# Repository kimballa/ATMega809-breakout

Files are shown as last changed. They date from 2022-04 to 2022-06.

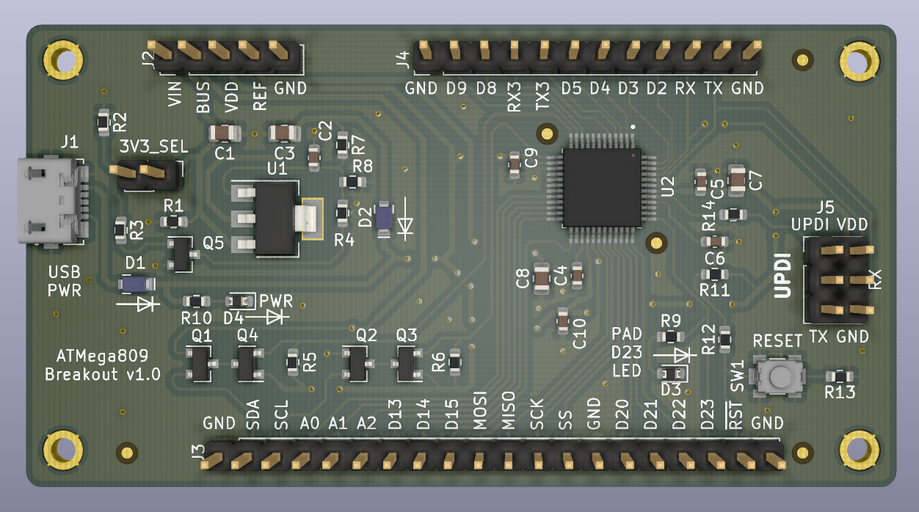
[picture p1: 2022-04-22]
fab runs/v1.0-2022-04-21/PCB-rendering.png

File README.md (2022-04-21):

# ATMega809 breakout board

PCB design for Atmel AVR ATMega809 breakout board. Capabilities compatible
with Arduino Nano Every (ATMega4809) and all other `ATMega{8/16/32/48}09`
and `x19` MCUs.

This provides more breakout pins from the 48-pin TQFP MCU than Nano Every
or other Arduinos.

## Power

Power can be supplied in 3 ways:

* The USB port `VUSB` is directly passed (unregulated) to the MCU
* Power on `VIN` will power a regulator that can operate at 5V0 or 3V3.
* Directly provide power to the `VDD` pin (unregulated)

### Caution!

Do not provide power to the regulator through `VIN` at the same time as
providing USB power through `VUSB`.

There are protection diodes so it should not immediately fail, but there is no
regulator shut-off circuit that detects USB power, so there may be unanticipated
consequences, especially if you plug in the USB power while the device is turned
on already by VIN.

This is especially true if the regulator is configured for 3V3, as the MCU will
immediately see its supply voltage increase while running.

`VDD` is also exposed on pin 15. You can use this to source power from the
linear regulator or to sink power back to the MCU. There is no diode or polyfuse
on this (or any) power bus of the device. Do not drive power into the device
through this pin at the same time as the regulator is powered.

### Configurable Regulator

The device is powered through an NCP1117LP adjustable 1A linear regulator.

This is configured for 5V0 operation by default. Closing the `3V3_SEL` jumper will
reconfigure it for 3V3. A task best performed with the device unpowered.

* If powering the device for 5V0, you must supply 6.5V or greater on `VIN`
* If powering the device for 3V3, you must supply 5.0V or greater on `VIN`
* `VIN` absolute maximum rating is 16V. For safe thermal operation, target
  `VDD + 3V` or less.

### Power limits and thermal capacity

You can draw power from the regulator's output `VDD` on pin 15. The total
power available (including MCU power budget) is 1A.

The ATMega809 can drive up to 15mA per pin in 5V0 mode, and 7.5mA in 3V3.
Absolute maximum rated drive per pin is +/-40mA. MCU absolute maximum VDD pin
input is 200mA.

The main limit to current is based on the LDO's thermal regulation capability.
LDO power dissipation in this implementation has an absolute maximum 825 mW. LDO
power dissipated is given by `(VIN - VDD - 0.35V)(IDD)`. Keeping `VIN` as close
to the 6.5V or 5.0V supply requirement gives more headroom for more current.

If VDD = 5V0 and VIN = 6V5, maximum current is 715 mA.

If VDD = 3V3 and VIN = 5V0, maximum current is 610 mA.

## Clock speed configuration

The MCU boots with `CLK_MAIN` driven by the `OSC20M` oscillator which is in
either 20MHz or 16MHz mode (check `OSCFUSE` bits to see how it is programmed),
with a `CLKDIV` of 6.

During boot, Arduino will disable the CLKDIV so your sketch is running at
the full 20 or 16MHz.

If operating in low-voltage 3V3 mode, the maximum safe clock speed is 10MHz.  So
a `CLKDIV` of at least 2 must be applied. If using an Arduino sketch on an
Arduino core compiled with default settings, the Arduino `init()` function will
fully unleash the clock divider for at least a short time before your `setup()`
method has time to pull it back to a divider of 2, which may cause boot
instability. Compiling the core with `-DFCPU=10000000` will tell Arduino to
unthrottle the clock only as far as a divider of 2.

## Level-shifting I2C Bus

The breakout board offers I2C on the `SDA`/`SCL` pins. A dual-transistor buffer
isolates the pull-up voltages seen on these pins from those seen by the MCU.
That is, a 3V3 network can communicate with an MCU operating at 5V0 or vice
versa.

You must supply power to the `VBUS` pin in order to activate the buffer and
communicate over I2C. Otherwise the external I2C bus will be fully isolated from
the MCU I2C bus. If the MCU and the external circuit are operating at the same
voltage you can connect `VBUS` to `VDD`.

You must apply external pull-up resistors to `SDA` and `SCL` to use I2C.
Typical resistor value is 4K7. The bus capacitance added by the breakout
board is typically 36 pF (per [PJA3438
datasheet](https://www.panjit.com.tw/upload/datasheet/PJA3438-AU.pdf))
[plus capacitance added by header pin, flying leads, etc].

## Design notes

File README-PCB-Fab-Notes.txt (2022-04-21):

Hello,

Thank you for making my PCB! I'm looking forward to seeing the results.

Here are a few manufacturing notes:

* U2 is 48-pin TQFP. 0.22mm between pins. Please eliminate solder dams in U2.

* USB Connector J1 goes right to the PCB edge. Molex MPN 0473461001. This does /not/ have flanges hanging down, it should lay flat on surface. Please let me know if this is a problem. 

* I have added 3 board fiducials and 2 local fiducials for U2. If these interfere with your localizing system I can remove them for you.

* Please note slightly rounded corners for edge milling.

If you have any questions, or there are difficulties to address please send me an email.

Thank you,
Aaron Kimball
akimball83@gmail.com

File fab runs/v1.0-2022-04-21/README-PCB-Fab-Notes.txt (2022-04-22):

Hello,

Thank you for making my PCB (ATMega809 Breakout)! I'm looking forward to seeing the results.

Here are a few manufacturing notes:

* U2 is 48-pin TQFP. 0.22mm space between pads. Please eliminate solder dams in U2.

* USB Connector J1 goes right to the PCB edge. Molex MPN 0473461001. This does /not/ have flanges hanging down, it should lay flat on surface. Please let me know if this is a problem. 

* I have added 3 board fiducials and 2 local fiducials for U2. If these interfere with your localizing system I can remove them for you and regenerate the files.

* For J2-J4 & JP1 assembly these just need cuttable male header pin strips of appropriate length. qty 39 is the total number of pins -- but only 4 strips/parts to place.

* Please note slightly rounded corners for edge milling.

* Part substitution for resistors is OK as long as they are 1% tolerance. For capacitors, LEDs, diodes, transistors etc. substitution only OK if all parameters in the "description" column in the BOM are met. The LEDs in particular are tuned for a very low test current requirement at 1.9V drop. The ATMEGA809 is acceptable in any of four part numbers: ATMEGA809-AF, ATMEGA809-AFR, ATMEGA809-AU, ATMEGA809-AUR. The -R's are on cut tape, AF/AU are in trays. This must be a genuine Microchip part.

I have included an electrical schematic pdf as well as a 3-d render of what the completed board should look like (png file). The BOM file (Excel) has a mapping from part ids to MPNs and descriptions. If you have any questions, or there are difficulties to address please send me an email.

Thank you,
Aaron Kimball
akimball83@gmail.com

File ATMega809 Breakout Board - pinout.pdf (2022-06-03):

## ATMega809 breakout board 24 digital I/O pins available

Pin | 16 | 15 | 14 | 13 | 12 | 11 | 10 | 9 | 8 | 7 | 6 | 5 | 4 | 3 | 2 | 1 | 0
Name | VIN | VBUS | VDD | VREF | GND | GND | D9 | D8 | RX0 | TX0 | D5 | D4 | D3 | D2 | RX1 | TX1 | GND
Timer/PWM | | | | | | | TCB3 | TCB2 | | | | | TCB1 | TCB0
Alt Name | | | | | | | RX2 | TX2 | D7 | D6 | EVOUTA | | | | D1 | D0
Mega-0 Pad | | | | | | | PC1 | PC0 | PB1 | PB0 | PA7 | PA6 | PA3 | PA2 | PA1 | PA0
Mega-0 Pad | | PC2 | PC3 | PD0 | PD1 | PD2 | PD3 | PD4 | PD5 | PE0 | PE1 | PE2 | PE3 | | PF0 | PF1 | PF2 | PF3 | PF6
Alt Name | | TWD | TWCK | D10 | D11 | D12/EVOUTD | A3 | A4 | A5 | D16/A6 | D17/A7 | D18/A8 | D19/A9 | | | | | LED
Timer/PWM | | | | TCA0 | TCA0 | TCA0 | TCA0 | TCA0 | TCA0
Name | GND | SDA | SCL | A0 | A1 | A2 | D13 | D14 | D15 | MOSI | MISO | SCK | SS | GND | D20 | D21 | D22 | D23 | RESET_L | GND
Pin | 17 | 18 | 19 | 20 | 21 | 22 | 23 | 24 | 25 | 26 | 27 | 28 | 29 | 30 | 31 | 32 | 33 | 34 | 35 | 36
Power | | VIN: Power to regulator; VDD: Power to MCU (from VIN, VUSB, or thru this pin); VBUS - I2C; VREF - Analog ref.
| Ground | | | | All pins except I2C and RESET_L support digital GPIO
I2C / TWI | | Level-shifting I2C bus; requires power on VBUS matching Vcc of communicating device/bus. | | EVENT outputs distributed throughout
| SPI | | SPI alt. position on PORTE | | TCA0 PWM output on D10..D15
| UART | | Serial port (Arduino HWSERIALn ) | | TCB0..3 PWM output on D2, D3, D8, D9
| Analog | | Analog input referenced against VREF | UPDI HEADER | See ATmega808/809/1608/1609 Data Sheet, section 4
CCL | 4x LUT inputs on Px0..2, output on Px3 | UPDI | VDD | v1.0
N/C | RX1 | 6-pin UPDI Header only requires UPDI and GND pins connected,
TX1 | GND | but offers ability to power MCU and use serial from programmer

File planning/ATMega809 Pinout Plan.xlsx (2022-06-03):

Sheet: Graphical pinout map
 | ATMega809 breakout board
 | 24 digital I/O pins available
Pin | 16 | 15 | 14 | 13 | 12 |  |  |  | 11 | 10 | 9 | 8 | 7 | 6 | 5 | 4 | 3 | 2 | 1 | 0
Name | VIN | VBUS | VDD | VREF | GND |  |  |  | GND | D9 | D8 | RX0 | TX0 | D5 | D4 | D3 | D2 | RX1 | TX1 | GND
Timer/PWM |  |  |  |  |  |  |  |  |  | TCB3 | TCB2 |  |  |  |  | TCB1 | TCB0
Alt Name |  |  |  |  |  |  |  |  |  | RX2 | TX2 | D7 | D6 | EVOUTA |  |  |  | D1 | D0
Mega-0 Pad |  |  |  |  |  |  |  |  |  | PC1 | PC0 | PB1 | PB0 | PA7 | PA6 | PA3 | PA2 | PA1 | PA0
Mega-0 Pad |  | PC2 | PC3 | PD0 | PD1 | PD2 | PD3 | PD4 | PD5 | PE0 | PE1 | PE2 | PE3 |  | PF0 | PF1 | PF2 | PF3 | PF6
Alt Name |  | TWD | TWCK | D10 | D11 | D12/EVOUTD | A3 | A4 | A5 | D16/A6 | D17/A7 | D18/A8 | D19/A9 |  |  |  |  | LED
Timer/PWM |  |  |  | TCA0 | TCA0 | TCA0 | TCA0 | TCA0 | TCA0
Name | GND | SDA | SCL | A0 | A1 | A2 | D13 | D14 | D15 | MOSI | MISO | SCK | SS | GND | D20 | D21 | D22 | D23 | RESET_L | GND
Pin | 17 | 18 | 19 | 20 | 21 | 22 | 23 | 24 | 25 | 26 | 27 | 28 | 29 | 30 | 31 | 32 | 33 | 34 | 35 | 36
Power | VIN: Power to regulator; VDD: Power to MCU (from VIN, VUSB, or thru this pin); VBUS - I2C; VREF - Analog ref.
Ground |  |  |  |  |  |  |  |  |  |  |  |  |  | All pins except I2C and RESET_L support digital GPIO
I2C / TWI | Level-shifting I2C bus; requires power on VBUS matching Vcc of communicating device/bus. |  |  |  |  |  |  |  |  |  |  |  |  | EVENT outputs distributed throughout
SPI | SPI alt. position on PORTE |  |  |  |  |  |  |  |  |  |  |  |  | TCA0 PWM output on D10..D15
UART | Serial port (Arduino HWSERIALn) |  |  |  |  |  |  |  |  |  |  |  |  | TCB0..3 PWM output on D2, D3, D8, D9
Analog | Analog input referenced against VREF |  |  |  |  |  | UPDI HEADER |  |  |  |  |  |  | See ATmega808/809/1608/1609 Data Sheet, section 4
CCL | 4x LUT inputs on Px0..2, output on Px3 |  |  |  |  |  | UPDI | VDD |  |  |  |  |  |  |  |  |  |  |  | v1.0
 |  |  |  |  |  |  | N/C | RX1 |  | 6-pin UPDI Header only requires UPDI and GND pins connected,
 |  |  |  |  |  |  | TX1 | GND |  | but offers ability to power MCU and use serial from programmer

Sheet: Planning
Pad | Pin | Nano Pad | Function | Alt fn | Trace | G'Duino |  | Pin | G'Duino
44 | PA0 | D2 | 0-IN0 | 0.TX |  | TX/D0 | implicitly free for link to LUT1 | PA0 | TX/D0
45 | PA1 | D7 | 0-IN1 | 0.RX | d7 | RX/D1 |  | PA1 | RX/D1
46 | PA2 | D18/A4 | 0-IN2 | MOSI,EVOUTA | dCLK (d10) | D2 | dCLK should be on 0-IN2 so it can CLK the output | PA2 | D2
47 | PA3 | D19/A5 | 0-OUT | MISO |  | D3 |  | PA3 | D3
 | PA6 |  |  | SCK |  | D4 |  | PA6 | D4
 | PA7 |  | CLKOUT | SS |  | D5 |  | PA7 | D5
 | PB0 |  | 3.TX |  |  | TX3/D6 |  | PB0 | TX3/D6
 | PB1 |  | 3.RX |  |  | RX3/D7 |  | PB1 | RX3/D7
10 | PC0 |  | 1-IN0 |  | d6 | D8 |  | PC0 | D8
11 | PC1 |  | 1-IN1 |  | d5 | D9 |  | PC1 | D9
12 | PC2 |  | SDA | 1-IN2 | SDA | SDA_MCU | 1-IN2 is feedback from LUT2 | PC2 | SDA_MCU
13 | PC3 |  | SCL |  |  | SCL_MCU |  | PC3 | SCL_MCU
20 | PD0 | D17/A3 | 2-IN0 |  | d3 | A0/D10 |  | PD0 | A0/D10
21 | PD1 | D16/A2 | 2-IN1 |  | d4 | A1/D11 |  | PD1 | A1/D11
22 | PD2 | D15/A1 | 2-IN2 | AC+0 | d0 | A2/D12 | duplicate d0 input for shift register, or feedback from LUT3. | PD2 | A2/D12
 | PD3 |  | 2-OUT | AC-0 |  | D13 |  | PD3 | D13
 | PD4 |  |  | AC+1 |  | D14 |  | PD4 | D14
 | PD5 |  |  | AC-1 |  | D15 |  | PD5 | D15
 | PE0 |  | MOSI |  |  | MOSI/D16 |  | PE0 | MOSI/D16
 | PE1 |  | MISO |  |  | MISO/D17 |  | PE1 | MISO/D17
 | PE2 |  | SCK |  |  | SCK/D18 |  | PE2 | SCK/D18
 | PE3 |  | SS |  |  | SS/D19 |  | PE3 | SS/D19
34 | PF0 |  | 3-IN0 |  | d0 | D20 |  | PF0 | D20
35 | PF1 |  | 3-IN1 |  | d1 | D21 |  | PF1 | D21
36 | PF2 | D18/A4 | 3-IN2 | SDA | d2 | D22 |  | PF2 | D22
37 | PF3 | D19/A5 | SCL(S) | 3-OUT |  | D23 | slave mode only??? … fine? | PF3 | D23
 | PF6 |  | RESET |  |  | RESET_L |  | PF6 | RESET_L

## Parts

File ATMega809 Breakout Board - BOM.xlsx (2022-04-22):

Part no. | Reference | Value | Datasheet | Description | Manufacturer | MPN | Qty | Comment
1 | C1, C3, C7, C8 | 10u |  | 10uF 0805 X5R or X7R ceramic capacitor; 20mOhm < ESR < 10 Ohm; V_max >= 10V | Samsung Electro-Mechanics | CL21A106KOQNNNG | 4
2 | C2, C4-C6, C9, C10 | 100n | https://datasheets.kyocera-avx.com/X7RDielectric.pdf | 100nF 0603 X7R ceramic capacitor; 20mOhm < ESR < 10 Ohm | KYOCERA | 06036C104JAT2A | 6
3 | D1, D2 | CUHS20S30 | https://toshiba.semicon-storage.com/info/docget.jsp?did=63606&prodName=CUHS20S30 | Schottky diode; V_R >= 30V; I_fwd >= 1A; 250mA < V_fwd < 340 mA @ 1A | Toshiba Semiconductor | CUHS20S30,H3F | 2
4 | D3, D4 | LTST-C193KRKT-2A | https://media.digikey.com/pdf/Data%20Sheets/Lite-On%20PDFs/LTST-C193KRKT-2A.pdf | Red chip LED; 0603; Vfwd = 1.8--2.0V, I_test = 2mA; >= 2mcd illumination @ 2mA | Lite-On | LTST-C193KRKT-2A | 2
5 | J1 | USB_B_Micro | https://www.molex.com/pdm_docs/sd/473461001_sd.pdf | USB Micro-B receptacle; SMT; no flanges; board-edge | Molex | 473461001 | 1
6 | J2-J4, JP1 |  | ~ | Cuttable male pin THT header strip (5, 20, 12, 2 pins), 0.1"/2.54mm pitch; 10--15.0µin gold plating; 0.230" mating, 0.10--0.11" post contact lengths | TE Connectivity AMP Connectors | 5-146858-1 | 39 | <-- total number of header pins; but only 4 parts (header strips) to place
7 | J5 | UPDI | ~ | Male pin THT header 2-row strip (2x3 pins), 0.1"/2.54mm pitch; 10--15.0µin gold plating | Samtec | TSW-103-07-L-D | 1
8 | Q1-Q5 | PJA3438-AU | https://www.panjit.com.tw/upload/datasheet/PJA3438-AU.pdf | N-MOSFET; SOT-23; I_D >= 500mA; max V_DS >= 50V; max V_GS +/-20V; 0.4V < V_GS(th) < 2.4V | Panjit Int'l. | PJA3438-AU_R1_000A1 | 5
9 | R3, R12, R13 | 1K0 | ~ | 1K0 0603 resistor; +/-1%; 1/10W | YAEGO | RC0603FR-071KL | 3
10 | R4 | 560R |  | 560R 0603 resistor; +/-1%; 1/10W | YAEGO | RC0603FR-07560RL | 1
11 | R5, R6 | 4K7 | ~ | 4K7 0603 resistor; +/-1%; 1/10W | YAEGO | RC0603FR-074K7L | 2
12 | R7 | 120R | ~ | 120R 0603 resistor; +/-1%; 1/10W | YAEGO | RC0603FR-07120RL | 1
13 | R8 | 390R | ~ | 390R 0603 resistor; +/-1%; 1/10W | YAEGO | RC0603FR-07390RL | 1
14 | R9, R10, R14 | 470R | ~ | 470R 0603 resistor; +/-1%; 1/10W | YAEGO | RC0603FR-07470RL | 3
15 | R1, R2, R11 | 100K | ~ | 100K 0603 resistor; +/-1%; 1/10W | YAEGO | RC0603FR-07100KL | 3
16 | SW1 | RESET | https://www.ckswitches.com/media/1474/pts820.pdf | Tactile momentary SPST (normally-open) switch/button; grounded. | C&K | PTS820 J25K SMTR LFS | 1
17 | U1 | NCP1117-ADJ_SOT223 | https://www.onsemi.com/pdf/datasheet/ncp1117lp-d.pdf | Adjustable linear regulator; SOT223 package; dropout voltage 1.3V @ 1A; V_in,max >= 12V | onsemi | NCP1117LPSTADT3G | 1
18 | U2 | ATMEGA809-AF |  | Critical component. ATMEGA809-AU also OK. -AFR and -AUR (tape & reel) packaging variants also OK. | Microchip | ATMEGA809-AF | 1

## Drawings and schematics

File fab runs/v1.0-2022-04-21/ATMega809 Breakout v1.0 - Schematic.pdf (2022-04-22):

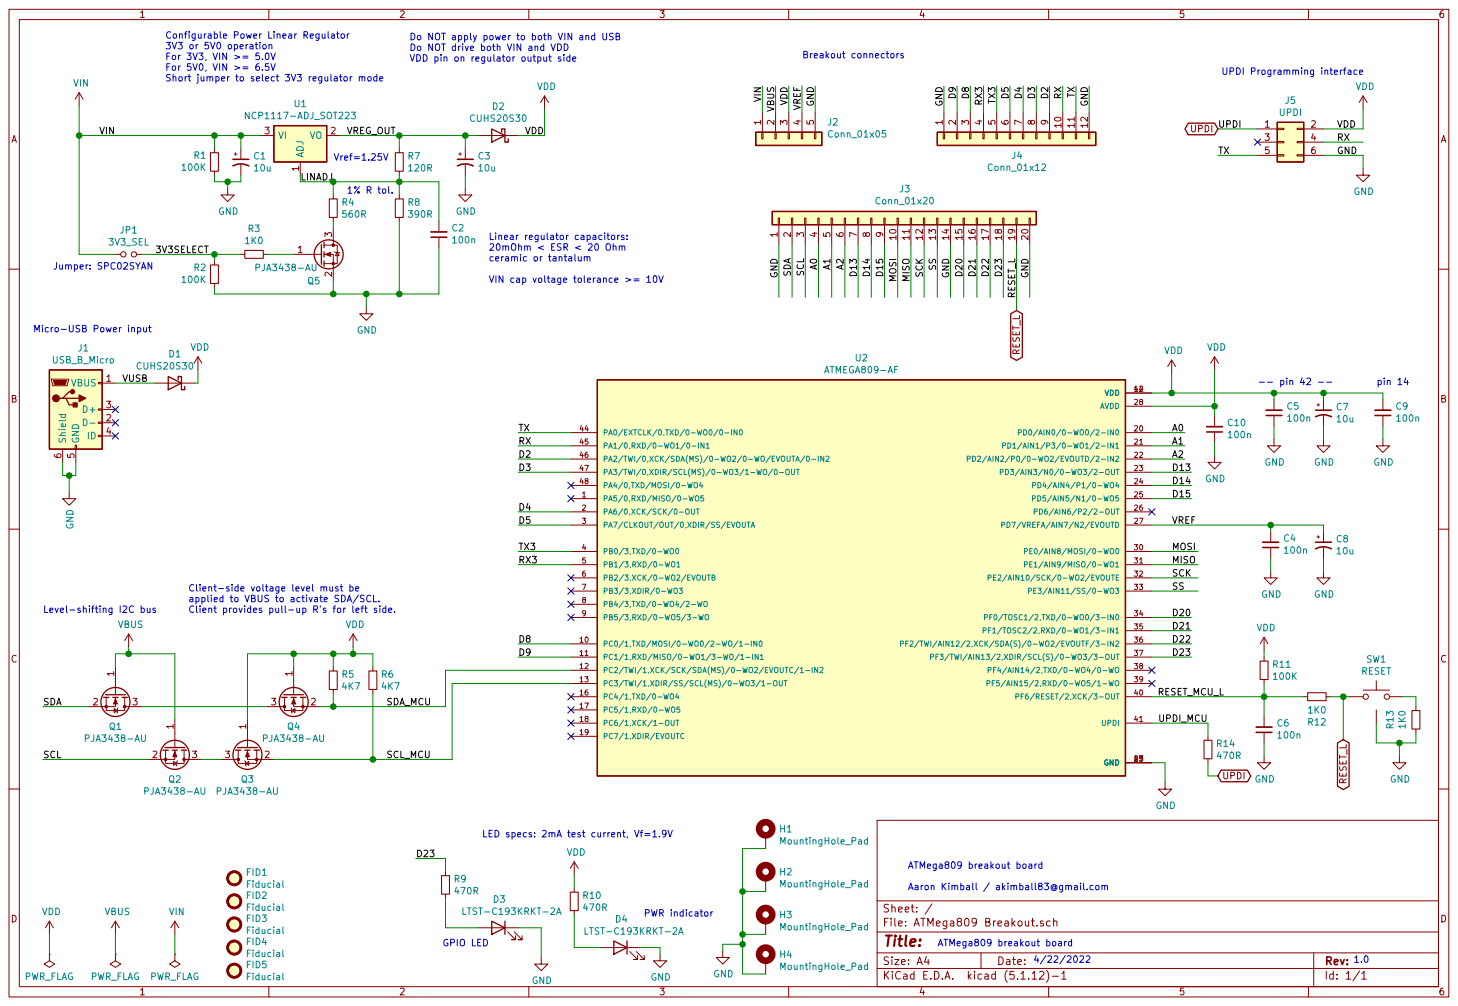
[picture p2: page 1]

Configurable Power Linear Regulator
3V3 or 5V0 operation For 3V3, VIN >= 5.0V
Breakout connectors Client-side voltage level must be
For 5V0, VIN >= 6.5V
Short jumper to select 3V3 regulator mode

Do NOT apply power to both VIN and USB Do NOT drive both VIN and VDD

VDD pin on regulator output side

SSD20 A1D22 D23 VREF VDD VBUS VIN

Linear regulator capacitors: 20mOhm < ESR < 20 Ohm

VIN cap voltage tolerance >= 10V

Micro-USB Power input

applied to VBUS to activate SDA/SCL.
Client provides pull-up R's for left side.

PWR indicator LED specs: 2mA test current, Vf=1.9V GPIO LED

Aaron Kimball / akimball83@gmail.com
File: ATMega809 Breakout.sch Sheet: /
Id: 1/1 Title:

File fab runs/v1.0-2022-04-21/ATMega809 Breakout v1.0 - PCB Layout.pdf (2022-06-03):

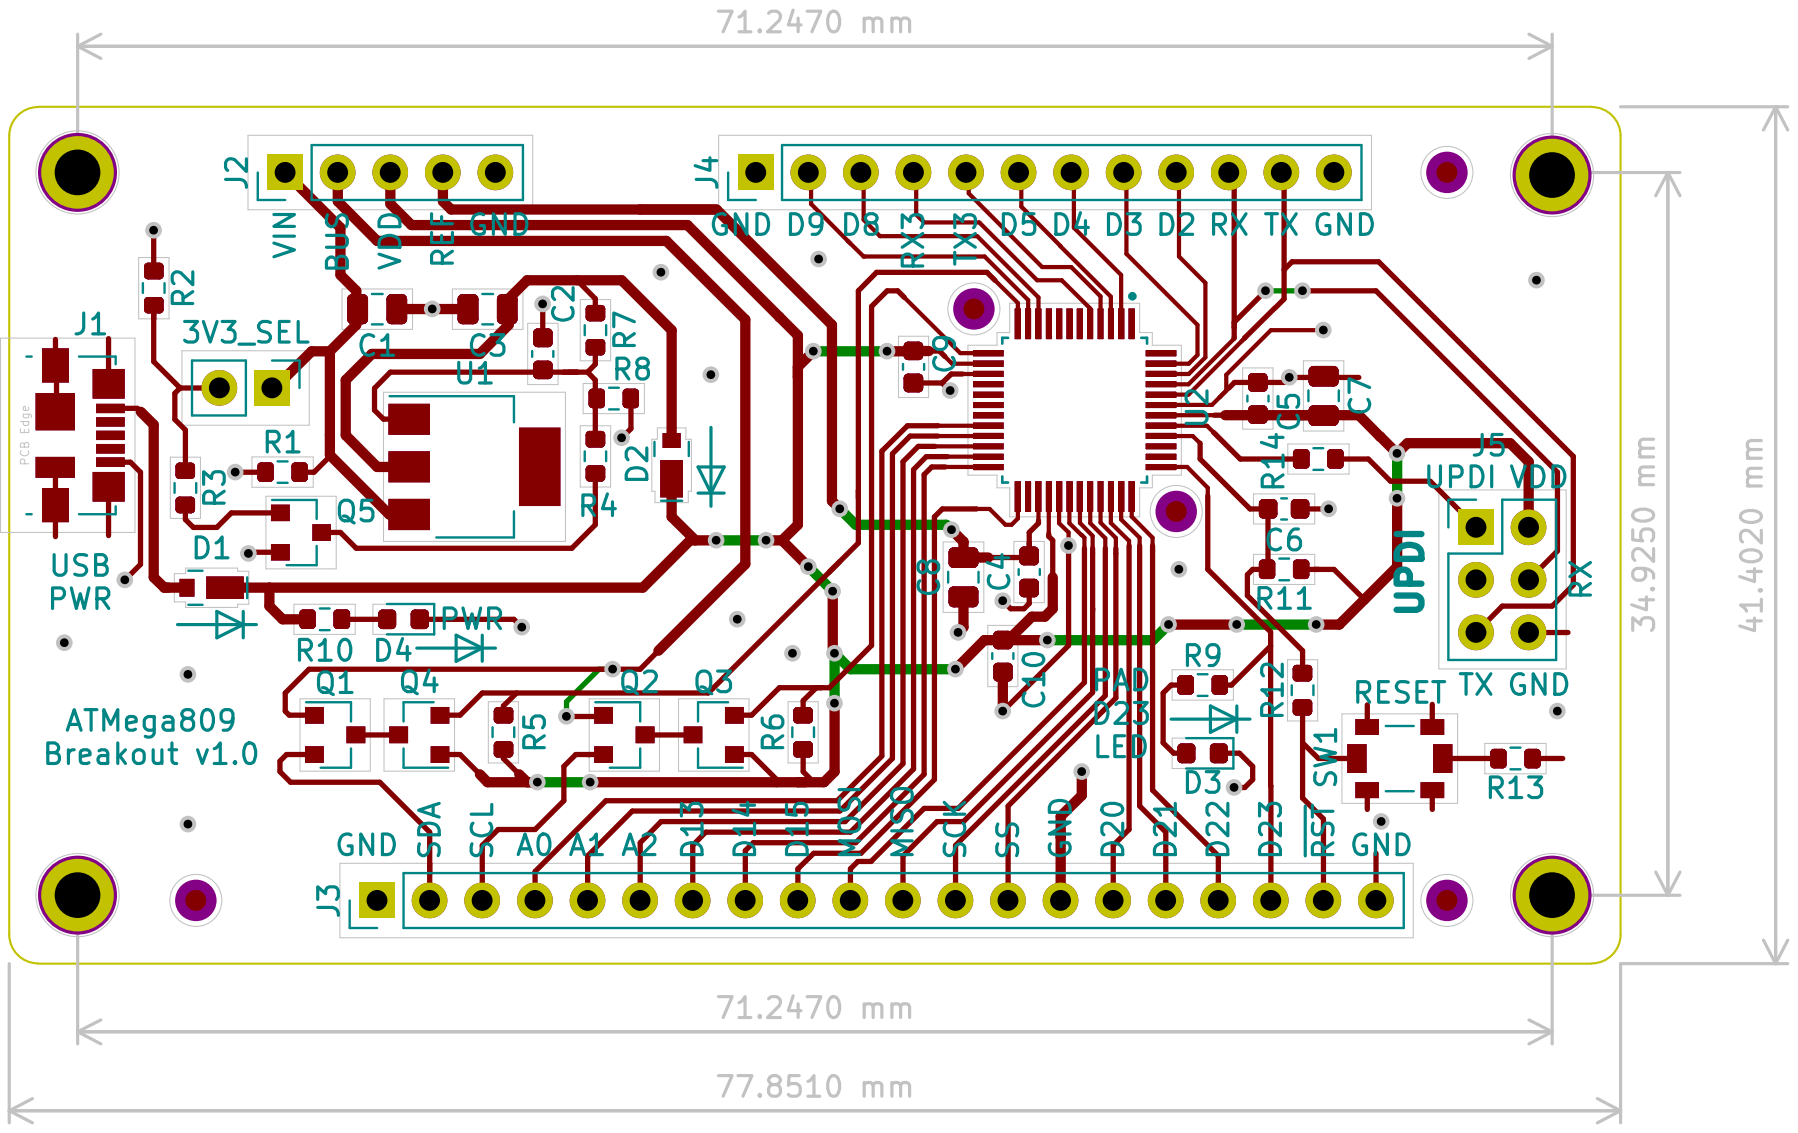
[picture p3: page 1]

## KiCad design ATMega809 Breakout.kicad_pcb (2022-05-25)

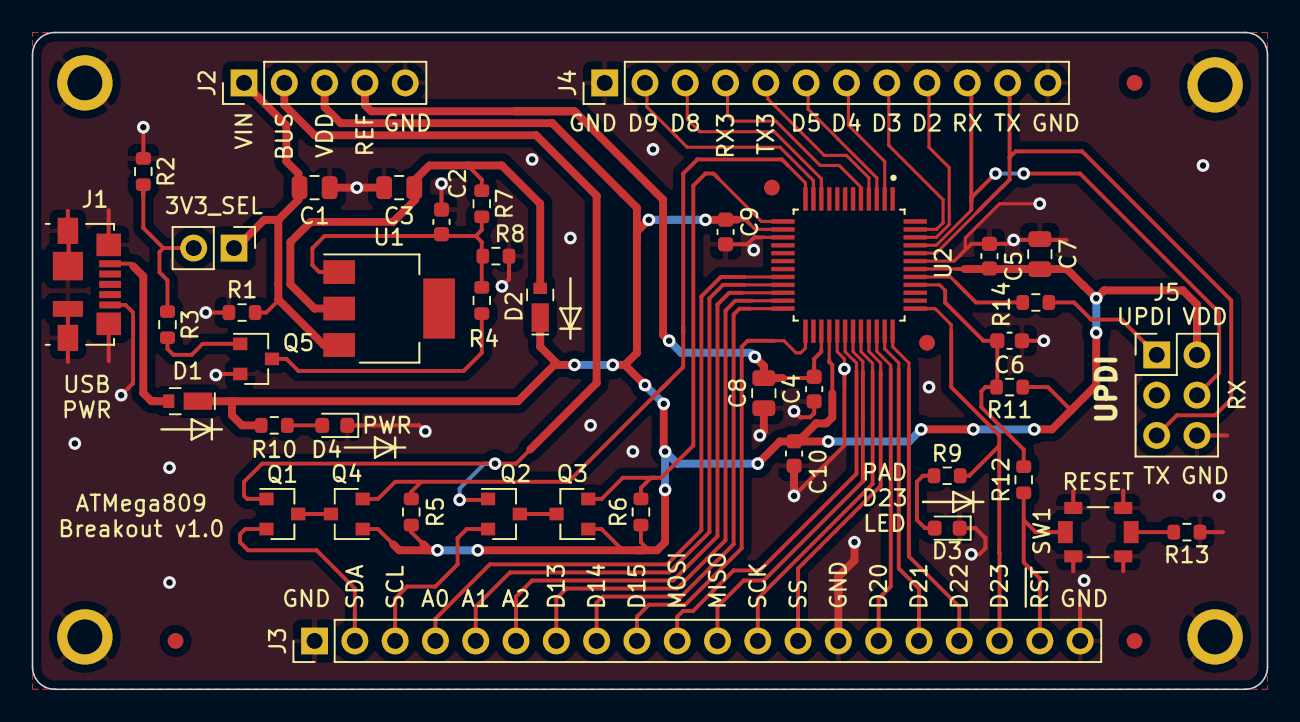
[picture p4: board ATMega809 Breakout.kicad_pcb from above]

Board: 2 copper layers, 77.9 x 41.4 mm, 51 parts (0 on the bottom side), 48 nets.

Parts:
C1, C3, C7, C8: 10u; C_0805_2012Metric
C2, C4, C5, C6, C9, C10: 100n; C_0603_1608Metric
D1, D2: CUHS20S30; CUHS20S30_H3F
D3, D4: LTST-C193KRKT-2A; D_0603_1608Metric
FID1, FID2, FID3, FID4, FID5: Fiducial; Fiducial_1mm_Mask2mm
H1, H2, H3, H4: MountingHole_Pad; MountingHole_2.2mm_M2_ISO7380_Pad
J1: USB_B_Micro; USB_Micro-B_Molex_47346-1001
J2: Conn_01x05; PinHeader_1x05_P2.54mm_Vertical
J3: Conn_01x20; PinHeader_1x20_P2.54mm_Vertical
J4: Conn_01x12; PinHeader_1x12_P2.54mm_Vertical
J5: UPDI; PinHeader_2x03_P2.54mm_Vertical
JP1: 3V3_SEL; PinHeader_1x02_P2.54mm_Vertical
Q1, Q2, Q3, Q4, Q5: PJA3438-AU; SOT-23
R1, R2, R11: 100K; R_0603_1608Metric
R3, R12, R13: 1K0; R_0603_1608Metric
R4: 560R; R_0603_1608Metric
R5, R6: 4K7; R_0603_1608Metric
R7: 120R; R_0603_1608Metric
R8: 390R; R_0603_1608Metric
R9, R10, R14: 470R; R_0603_1608Metric
SW1: RESET; PTS820_J25K_SMTR_LFS
U1: NCP1117-ADJ_SOT223; SOT-223
U2: ATMEGA809-AF; Microchip-TQFP7x7-48

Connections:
/3V3SELECT: JP1.2, R2.2, R3.1
/A0: J3.4, U2.20
/A1: J3.5, U2.21
/A2: J3.6, U2.22
/D2: J4.9, U2.46
/D3: J4.8, U2.47
/D4: J4.7, U2.2
/D5: J4.6, U2.3
/D8: J4.3, U2.10
/D9: J4.2, U2.11
/D13: J3.7, U2.23
/D14: J3.8, U2.24
/D15: J3.9, U2.25
/D20: J3.15, U2.34
/D21: J3.16, U2.35
/D22: J3.17, U2.36
/D23: J3.18, R9.1, U2.37
/LINADJ: C2.2, R4.1, R7.2, R8.1, U1.1
/MISO: J3.11, U2.31
/MOSI: J3.10, U2.30
/RESET_MCU_L: C6.2, R11.2, R12.2, U2.40
/RX: J4.10, J5.4, U2.45
/RX3: J4.4, U2.5
/SCK: J3.12, U2.32
/SCL: J3.3, Q2.2
/SCL_MCU: Q3.2, R6.2, U2.13
/SDA: J3.2, Q1.2
/SDA_MCU: Q4.2, R5.2, U2.12
/SS: J3.13, U2.33
/TX: J4.11, J5.5, U2.44
/TX3: J4.5, U2.4
/UPDI_MCU: R14.1, U2.41
/VREF: C4.2, C8.1, J2.4, U2.27
/VREG_OUT: C3.1, D2.2, R7.1, U1.2
/VUSB: D1.2, J1.1
GND: C1.2, C2.1, C3.2, C4.1, C5.1, C6.1, C7.2, C8.2, C9.1, C10.1, D3.1, D4.1, H1.1, H2.1, H3.1, H4.1, J1.5, J1.6, J2.5, J3.1, J3.14, J3.20, J4.1, J4.12, J5.6, Q5.2, R1.1, R2.1, R8.2, R13.1, SW1.3, U2.15, U2.29, U2.43
unnamed: D3.2, R9.2
unnamed: D4.2, R10.2
unnamed: Q1.3, Q4.3
unnamed: Q2.3, Q3.3
unnamed: Q5.1, R3.2
unnamed: Q5.3, R4.2
unnamed: R13.2, SW1.2
RESET_L: J3.19, R12.1, SW1.1
UPDI: J5.1, R14.2
VBUS: J2.2, Q1.1, Q2.1
VDD: C5.2, C7.1, C9.2, C10.2, D1.1, D2.1, J2.3, J5.2, Q3.1, Q4.1, R5.1, R6.1, R10.1, R11.1, U2.14, U2.28, U2.42
VIN: C1.1, J2.1, JP1.1, R1.2, U1.3

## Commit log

2022-04-20 Initial breakout board design checkin.
    Includes circuit schematic for MCU breakout, linear regulator,
    and level-shifting I2C bus.
    Includes prototype PCB layout.
    * Everything placed. Automated DRC checks pass.
    * Seeed D4M guidelines / checklist applied.
    [ATMega809 Breakout.kicad_pcb, ATMega809 Breakout.sch]
2022-04-20 Added notes file for PCB mfr.
2022-04-21 Cleanup. Basically ready for mfg.
    * Switched USB connectors to pure-SMT assembly, no THT.
    * More trace clean-ups. Eliminated 45 deg angles in traces.
    [ATMega809 Breakout.kicad_pcb, ATMega809 Breakout.sch]
2022-04-21 Improved RESET circuitry.
    * Switch SW1 now discharges capacitor C6 to GND thru R12 (1K0) rather
    than short-circuit.
    * Added resistor R13 (1K0) between RESET_L and pull-up R11/capacitor
    C6/SW1. If an external MCU drives RESET_L low, the capacitor will
    discharge through R13 rather than short circuit, limiting max
    discharge current encountered by the GPIO to 5mA.
    [ATMega809 Breakout.kicad_pcb, ATMega809 Breakout.sch]
2022-04-21 Add resistor R14 between UPDI_MCU and UPDI pin.
    If the MCU and programmer get out of sync and each try to drive the line
    in different directions, somebody's going to have a bad time. Small
    resistor ensures device safety while allowing high-speed bandwidth.
    Value is sufficiently low that even if the programmer also has a 470R
    on the line the logic levels will still work OK.
    See discussion:
    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
    [ATMega809 Breakout.kicad_pcb, ATMega809 Breakout.sch]
2022-04-21 Add decoupling cap C10 for AVDD pin of MCU.
    Add 100nF stabilizing ballast to AVDD input (MCU pin 28).
    [ATMega809 Breakout.kicad_pcb, ATMega809 Breakout.sch]
2022-04-21 Tweak RST protection resistor placement.
    [ATMega809 Breakout.kicad_pcb, ATMega809 Breakout.sch]
2022-04-21 Final tweaks and checks.
    [ATMega809 Breakout.kicad_pcb]
2022-04-22 v1.0 Release to manufacturing
    * Add BOM data to KiCAD and export to Excel.
    * Elaborate on fab notes TXT file.
    * Generate gerber files, schematic pdf, drill file, placement file for mfr.
    [ATMega809 Breakout Board - BOM.xlsx, ATMega809 Breakout.kicad_pcb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]
2022-04-22 Add v1.0 pin-out pdf.
    [ATMega809 Breakout Board - BOM.xlsx]
2022-04-22 Add pinout plan src excel file.
    [ATMega809 Pinout Plan.xlsx]
2022-05-25 Upgrade to KiCAD 6.0 format.
    [ATMega809 Breakout.kicad_pcb, ATMega809 Breakout.kicad_sch]
2022-05-27 Update pinout plan file.
    Reflect actual Arduino mapping.
    [ATMega809 Pinout Plan.xlsx]
2022-06-03 Update pinout to match the Arduino variant specification & add UDPI.
    [ATMega809 Pinout Plan.xlsx]
2022-06-03 Add pdf render of PCB layout for v1.0 run.
